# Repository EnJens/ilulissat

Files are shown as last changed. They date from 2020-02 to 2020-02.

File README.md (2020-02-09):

# Ilulissat
Ilulissat is a wireless environment sensor board, intended to run as low power as possible.

It consists of:
* [EFR32MG21](https://www.silabs.com/wireless/zigbee/efr32mg21-series-2-socs) Cortex M33 wireless chip
* [HDC2080](http://www.ti.com/product/HDC2080) Environment Sensor (Temperature and Relative Humidity)

The wireless chip supports both Bluetooth, Zigbee and OpenThread.

The first revision of the software will be written for Bluetooth Low energy using
a standard profile, e.g Temperature and Humidity, hopefully allowing it to use some standard
app off playstore/apple appstore.

## Images

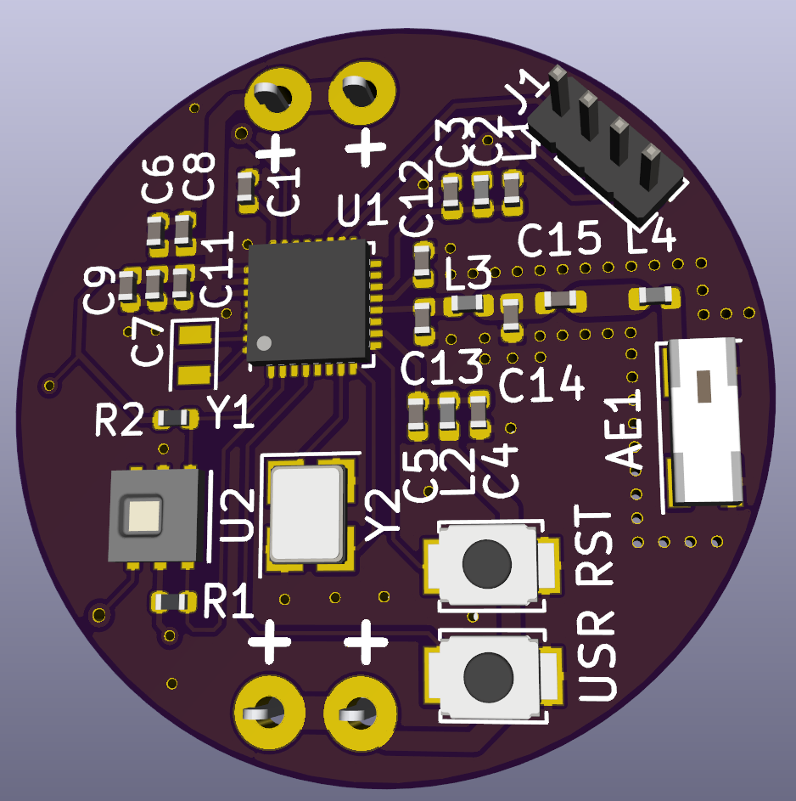
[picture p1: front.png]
PCB Front Front of board


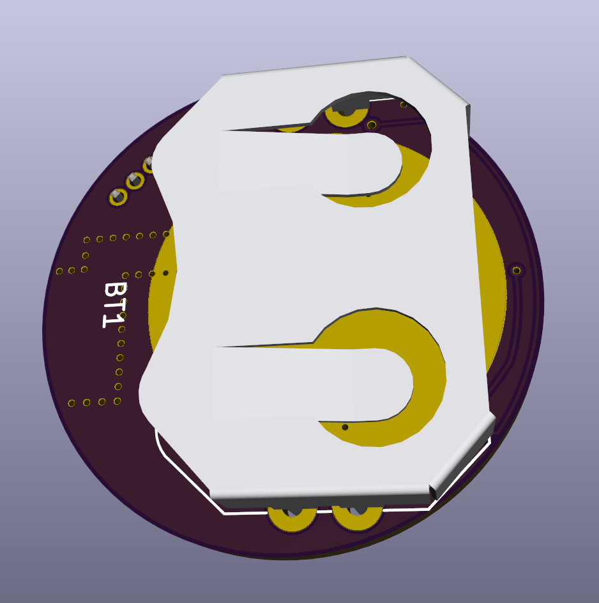
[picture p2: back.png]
PCB Back Back of board


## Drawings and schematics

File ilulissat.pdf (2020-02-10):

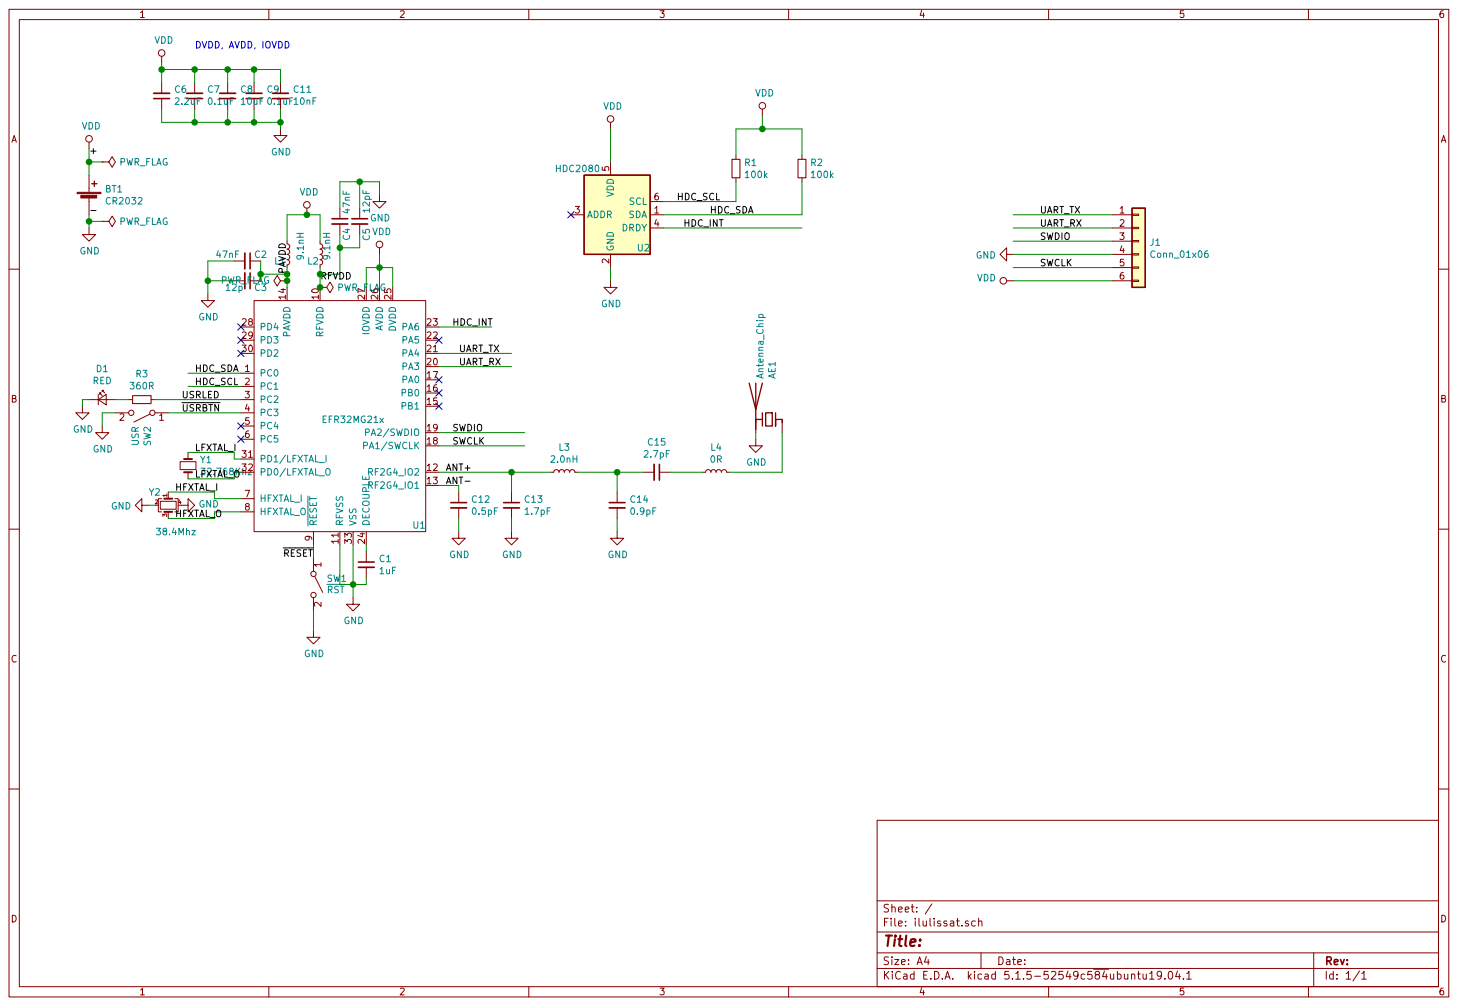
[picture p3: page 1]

Id: 1/1 Title: File: ilulissat.sch Sheet: /

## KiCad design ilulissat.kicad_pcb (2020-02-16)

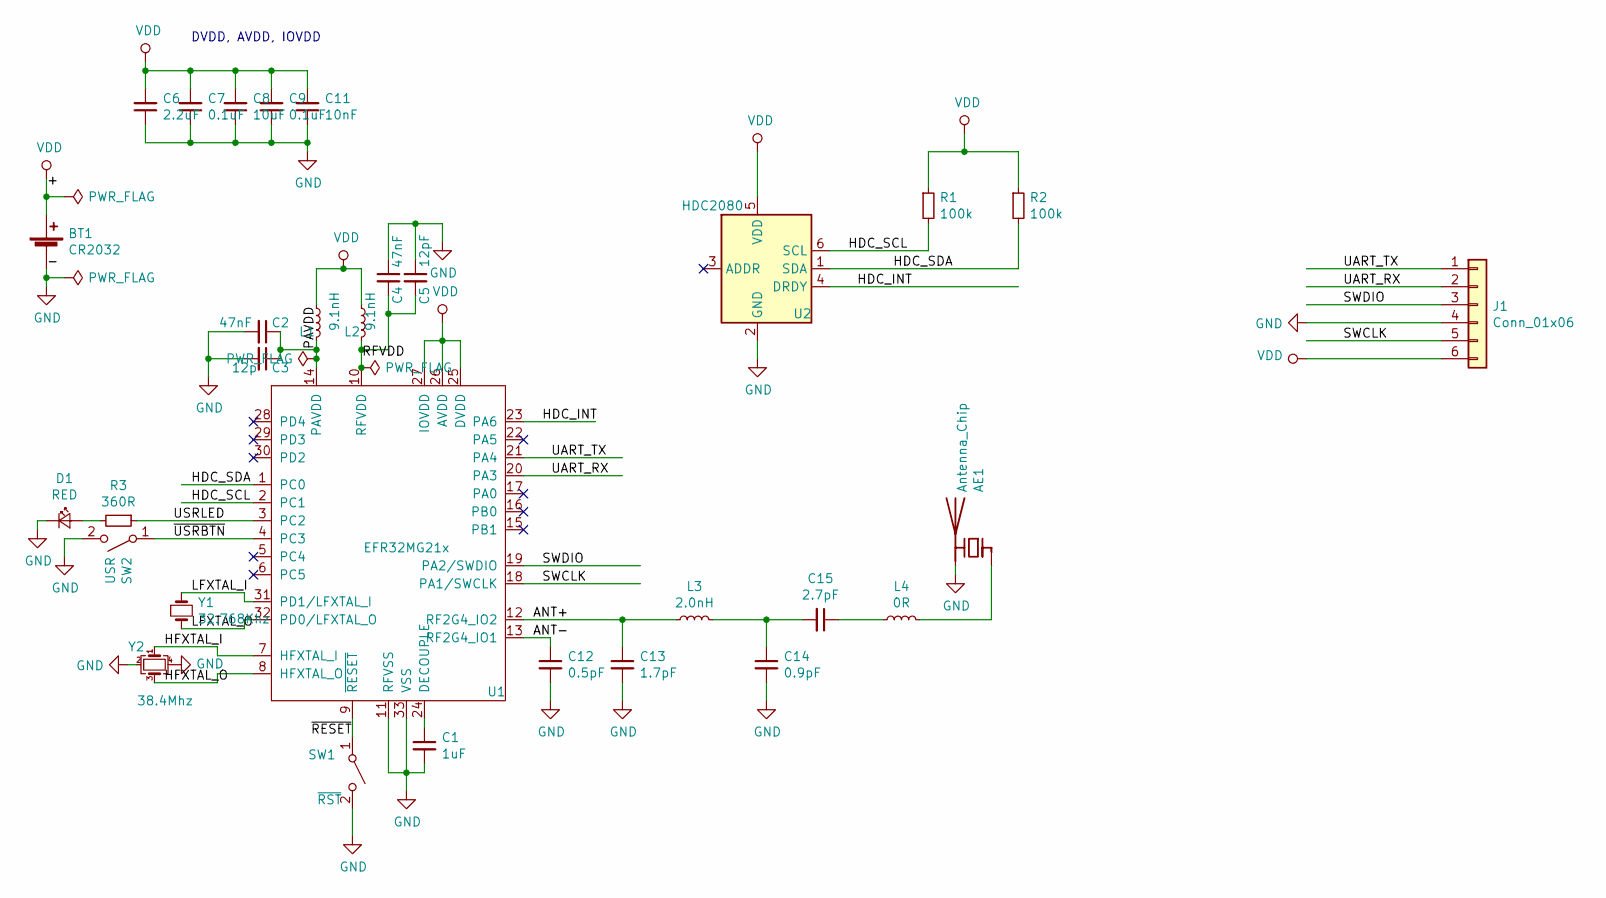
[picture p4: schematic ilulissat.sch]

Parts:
AE1: Antenna_Chip; Antenna_Johanson_2450AT42E0100; LCSC C127620
BT1: CR2032; BatteryHolder_Linx_BAT-HLD-001-THM
C1: 1uF; C_0402_1005Metric
C2, C4: 47nF; C_0402_1005Metric
C3: 12p; C_0402_1005Metric
C5: 12pF; C_0402_1005Metric
C6: 2.2uF; C_0402_1005Metric
C7, C9: 0.1uF; C_0402_1005Metric
C8: 10uF; C_0402_1005Metric
C11: 10nF; C_0402_1005Metric
C12: 0.5pF; C_0402_1005Metric
C13: 1.7pF; C_0402_1005Metric
C14: 0.9pF; C_0402_1005Metric
C15: 2.7pF; C_0402_1005Metric
D1: RED; LED_0402_1005Metric
J1: Conn_01x06; PinHeader_1x06_P1.27mm_Vertical
L1, L2: 9.1nH; L_0402_1005Metric; LCSC C281011
L3: 2.0nH; L_0402_1005Metric
L4: 0R; L_0402_1005Metric
R1, R2: 100k; R_0402_1005Metric
R3: 360R; R_0402_1005Metric
SW1: ~RST~; SW_SPST_B3U-1000P
SW2: USR; SW_SPST_B3U-1000P
U1: EFR32MG21x; QFN-32-1EP_4x4mm_P0.4mm_EP2.65x2.65mm
U2: HDC2080; Texas_PWSON-N6
Y1: 32.768Khz; Crystal_SMD_2012-2Pin_2.0x1.2mm; Mouser 520-.327-12.5-12R-T
Y2: 38.4Mhz; Crystal_SMD_3225-4Pin_3.2x2.5mm; Mouser 520-384-10-33B-CKYT

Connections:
/ANT+: C13.1, L3.1, U1.12 (RF2G4_IO2)
/ANT-: C12.1, U1.13 (RF2G4_IO1)
/HDC_INT: U1.23 (PA6), U2.4 (DRDY)
/HDC_SCL: R1.2, U1.2 (PC1), U2.6 (SCL)
/HDC_SDA: R2.2, U1.1 (PC0), U2.1 (SDA)
/HFXTAL_I: U1.7 (HFXTAL_I), Y2.1
/HFXTAL_O: U1.8 (HFXTAL_O), Y2.3
/LFXTAL_I: U1.31 (PD1/LFXTAL_I), Y1.1
/LFXTAL_O: U1.32 (PD0/LFXTAL_O), Y1.2
/PAVDD: C2.1, C3.1, L1.2, U1.14 (PAVDD)
/RFVDD: C4.2, C5.2, L2.2, U1.10 (RFVDD)
/SWCLK: J1.5, U1.18 (PA1/SWCLK)
/SWDIO: J1.3, U1.19 (PA2/SWDIO)
/UART_RX: J1.2, U1.20 (PA3)
/UART_TX: J1.1, U1.21 (PA4)
/USRLED: R3.1, U1.3 (PC2)
/~RESET~: SW1.1 (A), U1.9 (~RESET)
/~USRBTN~: SW2.1 (A), U1.4 (PC3)
GND: AE1.2 (PCB_Trace), BT1.2 (-), C1.2, C2.2, C3.2, C4.1, C5.1, C6.1, C7.1, C8.1, C9.1, C11.1, C12.2, C13.2, C14.2, D1.1 (K), J1.4, SW1.2 (B), SW2.2 (B), U1.11 (RFVSS), U1.33 (VSS), U2.2 (GND), Y2.2, Y2.4
unnamed: AE1.1 (FEED), L4.2
unnamed: C1.1, U1.24 (DECOUPLE)
unnamed: C14.1, C15.2, L3.2
unnamed: C15.1, L4.1
unnamed: D1.2 (A), R3.2
VDD: BT1.1 (+), C6.2, C7.2, C8.2, C9.2, C11.2, J1.6, L1.1, L2.1, R1.1, R2.1, U1.25 (DVDD), U1.26 (AVDD), U1.27 (IOVDD), U2.5 (VDD)

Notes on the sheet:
DVDD, AVDD, IOVDD

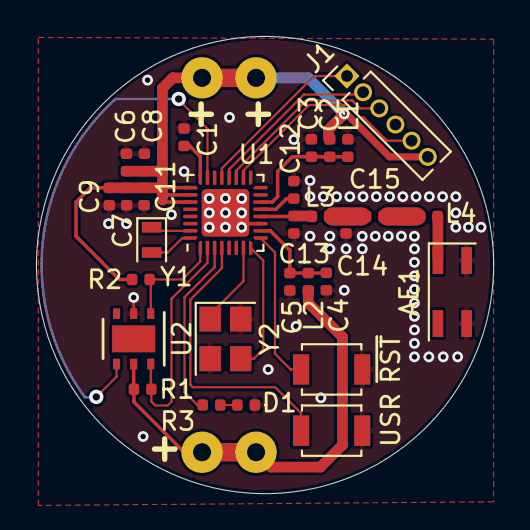
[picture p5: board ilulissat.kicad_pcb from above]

Board: 2 copper layers, 25.4 x 25.4 mm, 31 parts (1 on the bottom side), 25 nets.

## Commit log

2020-01-19 Initial project
    [ilulissat.kicad_pcb, ilulissat.sch]
2020-01-20 Start adding footprints, fill in remaining components
    [ilulissat.kicad_pcb, ilulissat.sch]
2020-01-21 More parts
    [ilulissat.sch]
2020-02-06 WIP WIP
    [ilulissat-B_Cu.gbr, ilulissat-B_Mask.gbr, ilulissat-B_Paste.gbr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]
2020-02-09 Routing complete, needs cleanup
    [ilulissat-B_Cu.gbr, ilulissat-B_Mask.gbr, ilulissat-B_Paste.gbr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]
2020-02-09 Don't track gerbers
    [ilulissat-B_Cu.gbr, ilulissat-B_Mask.gbr, ilulissat-B_Paste.gbr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]
2020-02-09 Round a track
    [ilulissat.kicad_pcb]
2020-02-09 Add a user button
    [ilulissat.kicad_pcb, ilulissat.sch]
2020-02-09 Add schematic PDF
2020-02-09 Fun tests
    [ilulissat.kicad_pcb, ilulissat.sch]
2020-02-09 Align some text
    [ilulissat.kicad_pcb]
2020-02-09 Update schematic PDF
2020-02-10 Add UART
    [ilulissat.kicad_pcb, ilulissat.sch]
2020-02-10 Add LED
    [ilulissat.kicad_pcb, ilulissat.sch]
2020-02-10 Make DRC unhappy for less risk of shorts
    [ilulissat.kicad_pcb]
2020-02-16 Rev 1 gerbers
    [ilulissat-B_Cu.gbr, ilulissat-B_Mask.gbr, ilulissat-B_Paste.gbr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]
